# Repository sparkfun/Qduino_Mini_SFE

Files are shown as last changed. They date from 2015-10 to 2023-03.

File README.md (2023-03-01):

Qduino Mini
========================================

Qduino Mini Qduino Mini top view (https://www.sparkfun.com/products/13614)

[*Qduino Mini - Arduino Dev Board (DEV-13614)*](https://www.sparkfun.com/products/13614)

The Qduino Mini is *perfect* to embed in your electronics projects, it's super small, inexpensive, has a battery connector & charger built-in, & a fuel gauge that can tell you when to charge the battery!

The **Qduino Mini is Arduino-compatible & 100% open source, hardware and software** meaning that making and programming your first circuit is a breeze.  Hardware is hard, so we decided to make it a little bit easier.  All of the design files, including EAGLE board files, schematic, and code have been released under an open source license.  Here's what it includes:

* **Battery Charger Circuit** - just plug in USB and it charges the battery with the auto switching circuit - there's no extra charger needed & no digging the battery out of your project so you can charge & program at the same time over USB!
* **Battery Fuel Gauge** - guessing on when your project runs out of juice?  We've got you covered - we have a simple monitor library for your battery so you can remind yourself when it needs a little extra juice.
* **Ultra small, Ultra thin, Ultra light** - The Qduino Mini itself is 0.8in x 1.5in (2cm x 3.9cm) & 0.18oz (5 grams), perfect for quadcopters, drones or high altitude balloon projects.  Both the Qduino Mini and the batteries (LiPos) used to power the board fit are super compact & thin, just right for embedding in your projects.

<h4>Tech Specs:</h4>

* **ATmega32U4 Processor** - Arduino Leonardo Compatible
* 32KB Flash Storage
* 2.5KB SRAM
* 1KB EEPROM
* 3.3V @ 8MHz
* 20 Digital I/O // 14 Dedicated
* 12 Analog Channels // 6 Dedicated
* 7 Digital I/O also PWM channels
* SPI, I2C, UART available
* Two RGB LEDs built-in - one for: Charge Status, TX, RX, and the * other user programmable
* **TPS78233** 3.3V 150mA Regulator
* **MCP73832** LiPo Battery Charger
* **MAX17048** LiPo Battery Fuel Gauge

The Qduino Mini is 100% made in the USA! Every board is made and quality tested at SparkFun Electronics, in Niwot, CO.

Documentation
--------------
* **[Introducing the Qduino Mini!](https://www.sparkfun.com/news/1754)** 
* **[Hookup Guide](https://www.hackster.io/team-qtechknow/qduino-mini-quickstart-guide-8b2d68)** - Basic hookup guide
* **[Hackster.io: Projects](https://www.hackster.io/qtechknow)** - Projects using the Qduino.
* **SparkFun: Projects**
  * **[DIY Light Sculpture](https://learn.sparkfun.com/tutorials/diy-light-sculpture)**
  * **[DIY Light-Up Shoes](https://learn.sparkfun.com/tutorials/diy-light-up-shoes)**
* **[SparkFun Arduino Board Add-on](https://github.com/sparkfun/Arduino_Boards)** - Board Add-on for the Qduino Mini
* **[SparkFun Fritzing Part](https://github.com/sparkfun/Fritzing_Parts/blob/main/products/13614_sfe_qtechknow_qduino_mini_arduino_development_board.fzpz)** - Fritzing diagrams for SparkFun products.
* **[SparkFun Graphical Datasheets](https://github.com/sparkfun/Graphical_Datasheets/tree/master/Datasheets/Qduino)** - Graphical Datasheets for various SparkFun products.

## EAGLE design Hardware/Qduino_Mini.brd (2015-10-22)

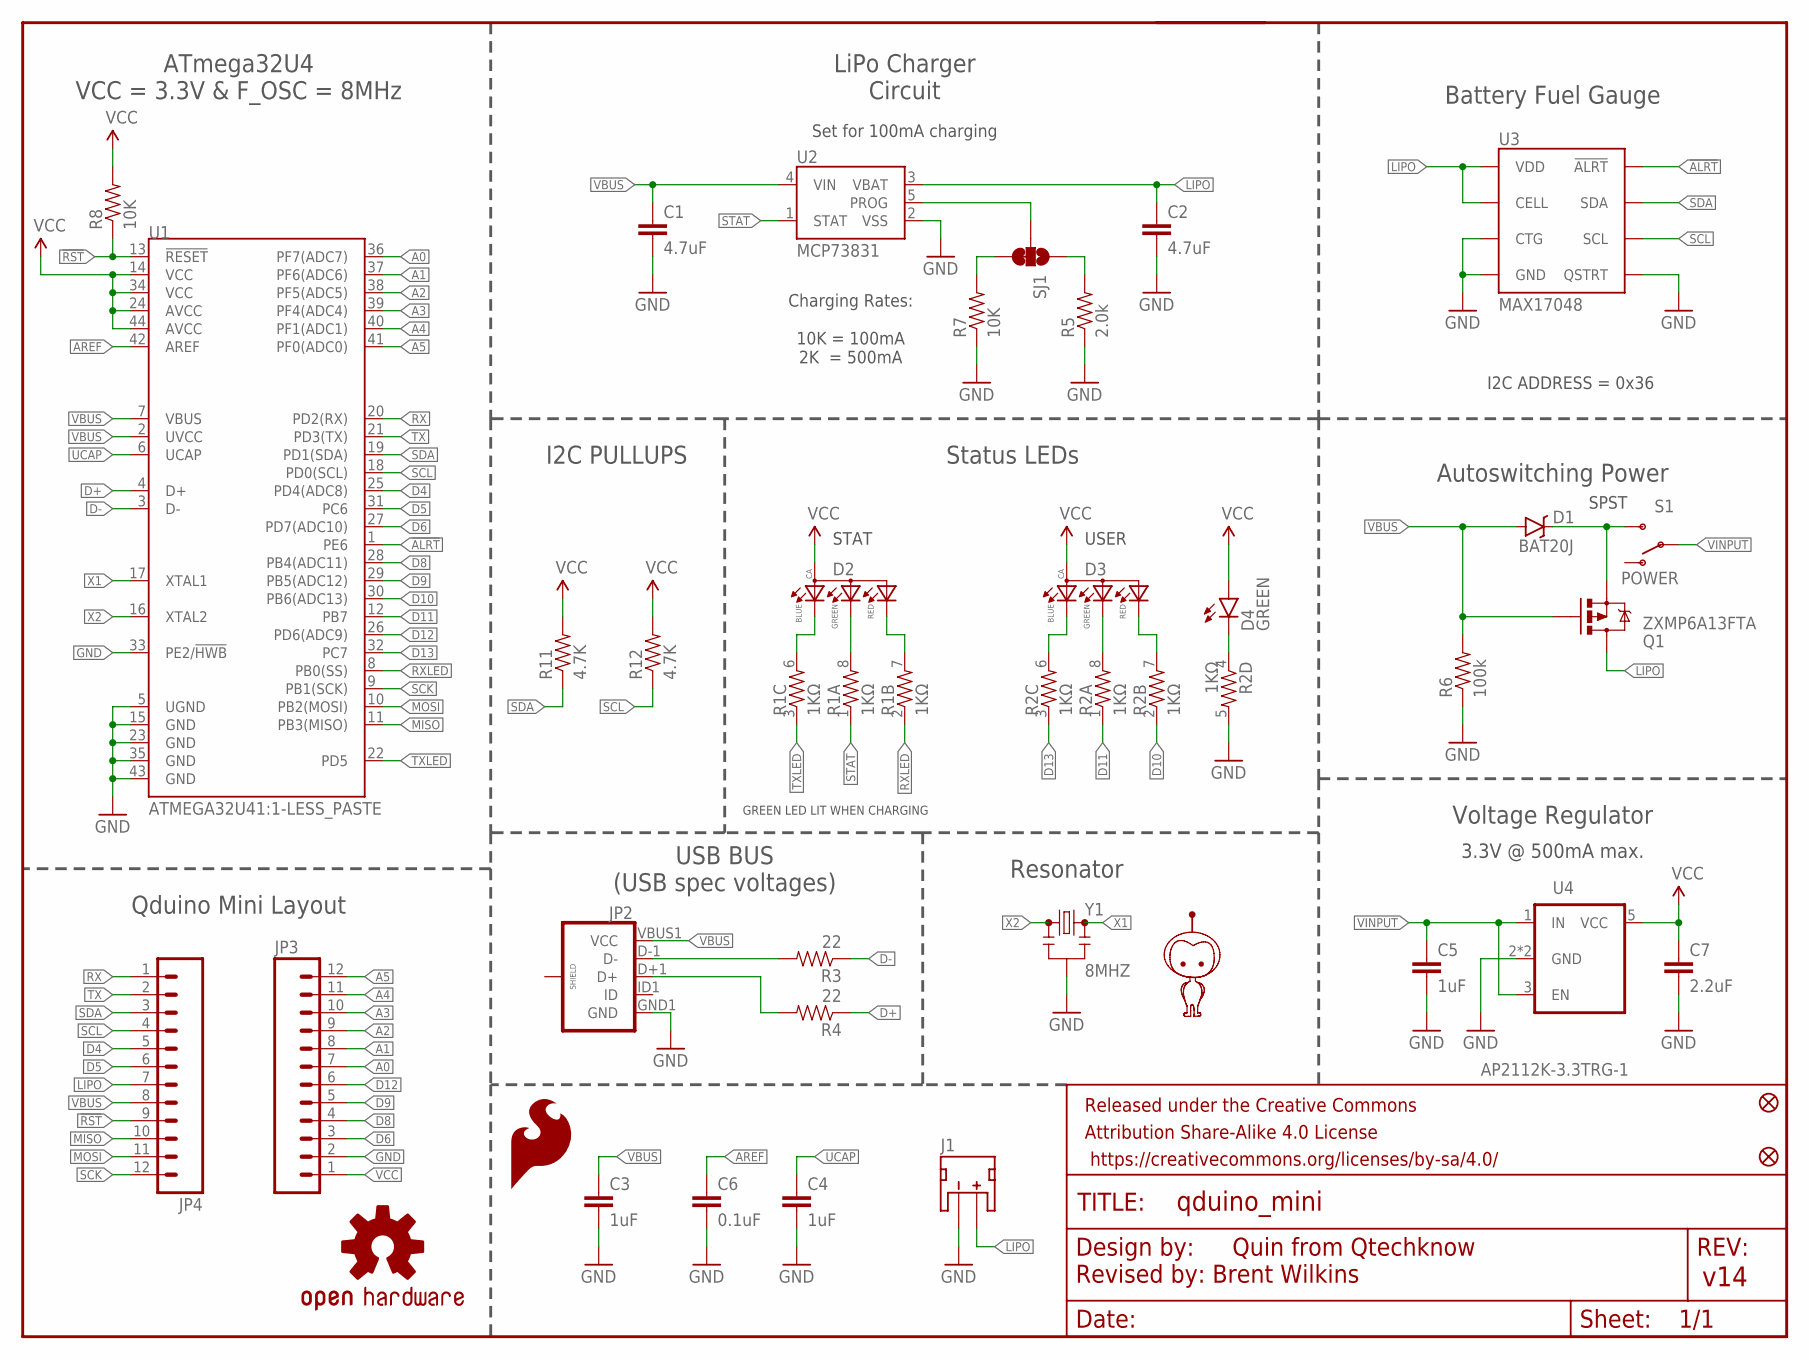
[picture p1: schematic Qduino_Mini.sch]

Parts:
C1, C2: 4.7uF; 0603-CAP
C3, C4, C5: 1uF; 0603-CAP
C6: 0.1uF; 0603-CAP
C7: 2.2uF; 0603-CAP
D1: BAT20J; SOD-323
D2, D3: 0.13_RGB_LEDPLCC; P-LCC-4-3
D4: GREEN; LED-0603
FID1, FID2: FIDUCIALUFIDUCIAL; MICRO-FIDUCIAL
FRAME2: FRAME-LETTER; CREATIVE_COMMONS
J1: LiPo; JST-2-SMD
JP2: USB_MICROB_PLUGCONN-11752; USB-B-MICRO-SMD_V03
JP3, JP4: M12PTH; 1X12
LOGO1: OSHW-LOGOS; OSHW-LOGO-S
LOGO2: SFE_LOGO_FLAME.1_INCH; SFE_LOGO_FLAME_.1
Q1: ZXMP6A13FTA; SOT23-3
R1, R2: 1KΩ; 0603-ARV
R3, R4: 22; 0603-RES
R5: 2.0k; 0603-RES
R6: 100k; 0603-RES
R7, R8: 10K; 0603-RES
R11, R12: 4.7K; 0603-RES
S1: POWER; SWITCH-SPST-SMD-A
SJ1: JUMPER-PAD-3-2OF3_NC_BY_TRACE_SMALL; PAD-JUMPER-3-2OF3_NC_BY_TRACE_YES_SILK_FULL_BOX
U1: ATMEGA32U41:1-LESS_PASTE; QFN-44-NOPAD_1:1-LESS_PASTE
U2: MCP73831; SOT23-5
U3: MAX17048; DFN-8
U4: AP2112K-3.3TRG-1; SOT23-5
U5: MIGHTYQ-L-SILK; LOGO-LARGE-SILK
Y1: 8MHZ; RESONATOR-SMD

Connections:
!ALRT: U1.1 (PE6), U3.P$5 (!ALRT)
!RST: JP4.9, R8.1, U1.13 (!RESET)
A0: JP3.7, U1.36 (PF7(ADC7))
A1: JP3.8, U1.37 (PF6(ADC6))
A2: JP3.9, U1.38 (PF5(ADC5))
A3: JP3.10, U1.39 (PF4(ADC4))
A4: JP3.11, U1.40 (PF1(ADC1))
A5: JP3.12, U1.41 (PF0(ADC0))
AREF: C6.1, U1.42 (AREF)
D4: JP4.5, U1.25 (PD4(ADC8))
D5: JP4.6, U1.31 (PC6)
D6: JP3.3, U1.27 (PD7(ADC10))
D8: JP3.4, U1.28 (PB4(ADC11))
D9: JP3.5, U1.29 (PB5(ADC12))
D10: R2.2 (1), U1.30 (PB6(ADC13))
D11: R2.1, U1.12 (PB7)
D12: JP3.6, U1.26 (PD6(ADC9))
D13: R2.3 (1), U1.32 (PC7)
D+: R4.1, U1.4 (D+)
D-: R3.1, U1.3 (D-)
GND: C1.2, C2.2, C3.2, C4.2, C5.2, C6.2, C7.2, J1.1 (-), JP2.GND1 (GND), JP3.2, R2.5 (2), R5.1, R6.1, R7.1, U1.5 (UGND), U1.15 (GND), U1.23 (GND), U1.33 (PE2/!HWB), U1.35 (GND), U1.43 (GND), U2.2 (VSS), U3.P$1 (CTG), U3.P$4 (GND), U3.P$6 (QSTRT), U3.P$9 (GND), U4.2 (GND), U4.4 (GND), Y1.2
INMOSFET: D1.C, Q1.2 (S), S1.3 (S)
LIPO: C2.1, J1.2 (+), JP4.7, Q1.3 (D), U2.3 (VBAT), U3.P$2 (CELL), U3.P$3 (VDD)
MISO: JP4.10, U1.11 (PB3(MISO))
MOSI: JP4.11, U1.10 (PB2(MOSI))
unnamed: D2.3 (BLUE), R1.6 (2)
unnamed: D2.2 (GREEN), R1.8 (2)
unnamed: D3.3 (BLUE), R2.6 (2)
unnamed: D4.C, R2.4 (1)
unnamed: R7.2, SJ1.3
unnamed: R5.2, SJ1.1
unnamed: D3.2 (GREEN), R2.8 (2)
unnamed: D2.1 (RED), R1.7 (2)
unnamed: D3.1 (RED), R2.7 (2)
PROG: SJ1.2, U2.5 (PROG)
RX: JP4.1, U1.20 (PD2(RX))
RXLED: R1.2 (1), U1.8 (PB0(SS))
SCK: JP4.12, U1.9 (PB1(SCK))
SCL: JP4.4, R12.1, U1.18 (PD0(SCL)), U3.P$7 (SCL)
SDA: JP4.3, R11.1, U1.19 (PD1(SDA)), U3.P$8 (SDA)
STAT: R1.1, U2.1 (STAT)
TX: JP4.2, U1.21 (PD3(TX))
TXLED: R1.3 (1), U1.22 (PD5)
UCAP: C4.1, U1.6 (UCAP)
UD+: JP2.D+1 (D+), R4.2
UD-: JP2.D-1 (D-), R3.2
VBUS: C1.1, C3.1, D1.A, JP2.VBUS1 (VCC), JP4.8, Q1.1 (G), R6.2, U1.2 (UVCC), U1.7 (VBUS), U2.4 (VIN)
VCC: C7.1, D2.4 (ANODE), D3.4 (ANODE), D4.A, JP3.1, R8.2, R11.2, R12.2, U1.14 (VCC), U1.24 (AVCC), U1.34 (VCC), U1.44 (AVCC), U4.5 (VCC)
VINPUT: C5.1, S1.2, U4.1 (IN), U4.3 (EN)
X1: U1.17 (XTAL1), Y1.3
X2: U1.16 (XTAL2), Y1.1

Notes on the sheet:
Set for 100mA charging
USB BUS (USB spec voltages)
Resonator
Status LEDs
3.3V @ 500mA max.
SPST
ATmega32U4 VCC = 3.3V & F_OSC = 8MHz
Qduino Mini Layout
LiPo Charger Circuit
Battery Fuel Gauge
Voltage Regulator
Autoswitching Power
Charging Rates: 10K = 100mA 2K = 500mA
I2C PULLUPS
Revised by: Brent Wilkins
I2C ADDRESS = 0x36
USER
STAT
GREEN LED LIT WHEN CHARGING

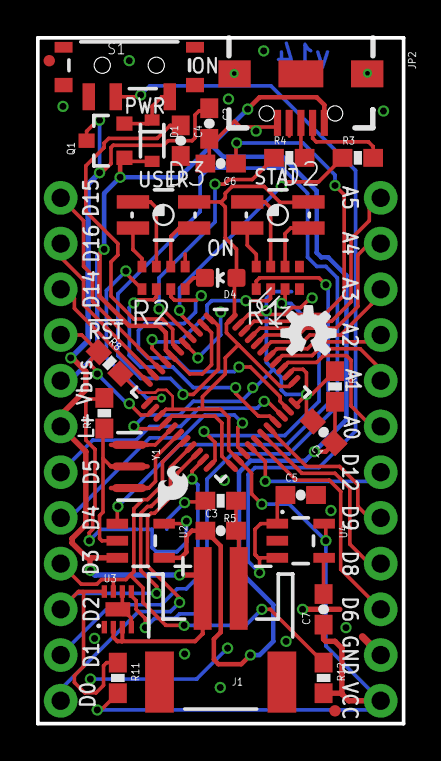
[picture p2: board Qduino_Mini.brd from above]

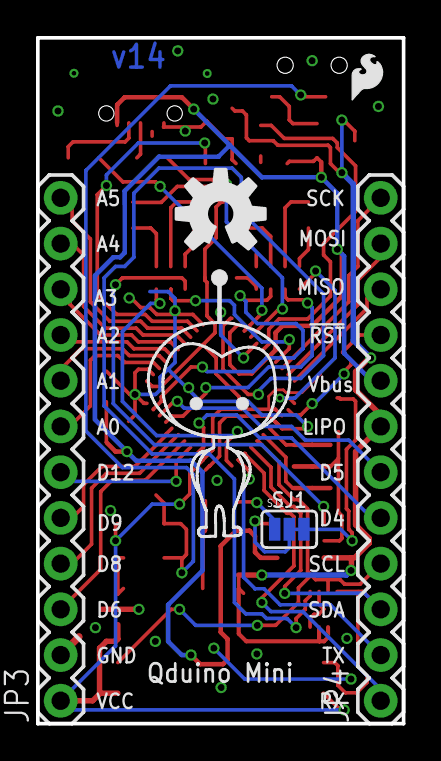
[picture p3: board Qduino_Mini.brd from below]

Board: 2 copper layers, 20.3 x 38.1 mm, 41 parts (6 on the bottom side), 51 nets.

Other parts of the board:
LOGO3: SFE_LOGO_FLAME.1_INCH; SFE_LOGO_FLAME_.1@1
U$4: OSHW-LOGO-M@1

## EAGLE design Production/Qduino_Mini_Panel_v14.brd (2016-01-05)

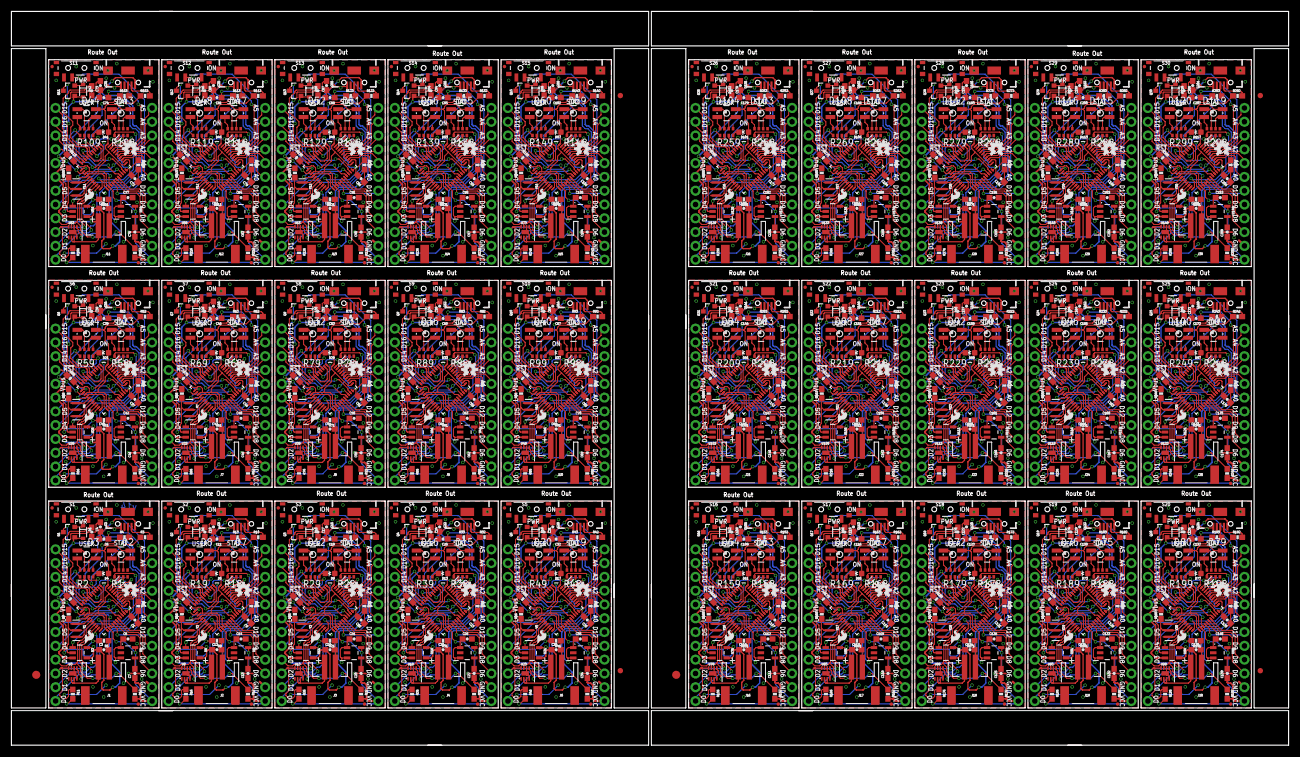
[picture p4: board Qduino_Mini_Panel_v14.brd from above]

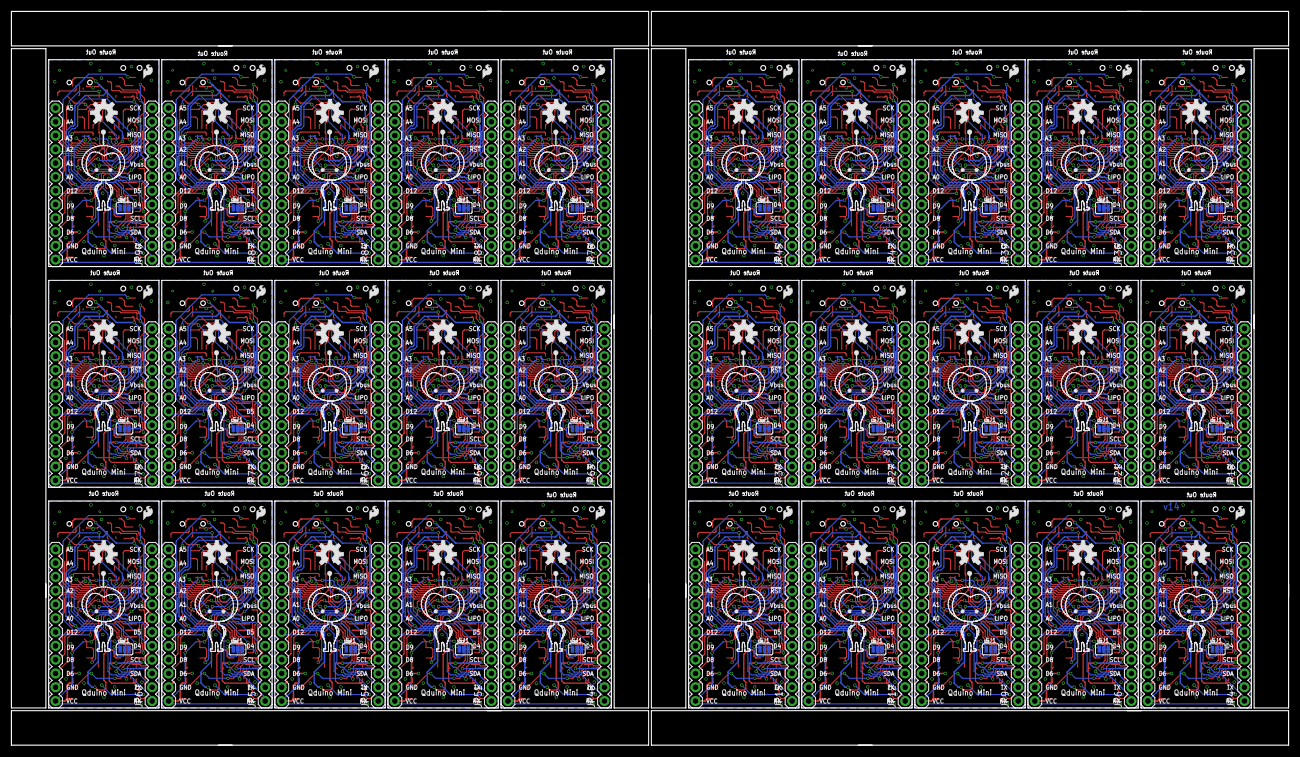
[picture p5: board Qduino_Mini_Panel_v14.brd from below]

Board: 2 copper layers, 235.2 x 135.1 mm, 1206 parts (180 on the bottom side), 1530 nets.

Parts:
C1, C2, C8, C9, C15, C16, C22, C23, C29, C30, C36, C37, C43, C44, C50, C51, C57, C58, C64, C65, C71, C72, C78, C79, C85, C86, C92, C93, C99, C100, C106, C107, C113, C114, C120, C121, C127, C128, C134, C135, C141, C142, C148, C149, C155, C156, C162, C163, C169, C170, C176, C177, C183, C184, C190, C191, C197, C198, C204, C205: 4.7uF; 0603-CAP
C3, C4, C5, C10, C12, C14, C17, C19, C21, C24, C26, C28, C31, C33, C35, C38, C40, C42, C45, C47, C49, C52, C54, C56, C59, C61, C63, C66, C68, C70, C73, C75, C77, C80, C82, C84, C87, C89, C91, C94, C96, C98, C101, C103, C105, C108, C110, C112, C115, C117, C119, C122, C124, C126, C129, C131, C133, C136, C138, C140, C143, C145, C147, C150, C152, C154, C157, C159, C161, C164, C166, C168, C171, C173, C175, C178, C180, C182, C185, C187, C189, C192, C194, C196, C199, C201, C203, C206, C208, C210: 1uF; 0603-CAP
C6, C11, C18, C25, C32, C39, C46, C53, C60, C67, C74, C81, C88, C95, C102, C109, C116, C123, C130, C137, C144, C151, C158, C165, C172, C179, C186, C193, C200, C207: 0.1uF; 0603-CAP
C7, C13, C20, C27, C34, C41, C48, C55, C62, C69, C76, C83, C90, C97, C104, C111, C118, C125, C132, C139, C146, C153, C160, C167, C174, C181, C188, C195, C202, C209: 2.2uF; 0603-CAP
D1, D6, D10, D14, D18, D22, D26, D30, D34, D38, D42, D46, D50, D54, D58, D62, D66, D70, D74, D78, D82, D86, D90, D94, D98, D102, D106, D110, D114, D118: BAT20J; SOD-323
D2, D3, D7, D8, D11, D12, D15, D16, D19, D20, D23, D24, D27, D28, D31, D32, D35, D36, D39, D40, D43, D44, D47, D48, D51, D52, D55, D56, D59, D60, D63, D64, D67, D68, D71, D72, D75, D76, D79, D80, D83, D84, D87, D88, D91, D92, D95, D96, D99, D100, D103, D104, D107, D108, D111, D112, D115, D116, D119, D120: P-LCC-4-3
D4, D5, D9, D13, D17, D21, D25, D29, D33, D37, D41, D45, D49, D53, D57, D61, D65, D69, D73, D77, D81, D85, D89, D93, D97, D101, D105, D109, D113, D117: GREEN; LED-0603
E$1, E$4: FIDUCIAL-1.5X3
E$2, E$3, E$5, E$6: FIDUCIAL-1X2
FID1, FID2, FID3, FID4, FID5, FID6, FID7, FID8, FID9, FID10, FID11, FID12, FID13, FID14, FID15, FID16, FID17, FID18, FID19, FID20, FID21, FID22, FID23, FID24, FID25, FID26, FID27, FID28, FID29, FID30, FID31, FID32, FID33, FID34, FID35, FID36, FID37, FID38, FID39, FID40, FID41, FID42, FID43, FID44, FID45, FID46, FID47, FID48, FID49, FID50, FID51, FID52, FID53, FID54, FID55, FID56, FID57, FID58, FID59, FID60: FIDUCIALUFIDUCIAL; MICRO-FIDUCIAL
J1, J2, J3, J4, J5, J6, J7, J8, J9, J10, J11, J12, J13, J14, J15, J16, J17, J18, J19, J20, J21, J22, J23, J24, J25, J26, J27, J28, J29, J30: LiPo; JST-2-SMD
JP1, JP2, JP7, JP10, JP13, JP16, JP19, JP22, JP25, JP28, JP31, JP34, JP37, JP40, JP43, JP46, JP49, JP52, JP55, JP58, JP61, JP64, JP67, JP70, JP73, JP76, JP79, JP82, JP85, JP88: USB-B-MICRO-SMD_V03
JP3, JP4, JP5, JP6, JP8, JP9, JP11, JP12, JP14, JP15, JP17, JP18, JP20, JP21, JP23, JP24, JP26, JP27, JP29, JP30, JP32, JP33, JP35, JP36, JP38, JP39, JP41, JP42, JP44, JP45, JP47, JP48, JP50, JP51, JP53, JP54, JP56, JP57, JP59, JP60, JP62, JP63, JP65, JP66, JP68, JP69, JP71, JP72, JP74, JP75, JP77, JP78, JP80, JP81, JP83, JP84, JP86, JP87, JP89, JP90: 1X12
LOGO1, LOGO4, LOGO7, LOGO10, LOGO13, LOGO16, LOGO19, LOGO22, LOGO25, LOGO28, LOGO31, LOGO34, LOGO37, LOGO40, LOGO43, LOGO46, LOGO49, LOGO52, LOGO55, LOGO58, LOGO61, LOGO64, LOGO67, LOGO70, LOGO73, LOGO76, LOGO79, LOGO82, LOGO85, LOGO88: OSHW-LOGOS; OSHW-LOGO-S
LOGO2, LOGO5, LOGO8, LOGO11, LOGO14, LOGO17, LOGO20, LOGO23, LOGO26, LOGO29, LOGO32, LOGO35, LOGO38, LOGO41, LOGO44, LOGO47, LOGO50, LOGO53, LOGO56, LOGO59, LOGO62, LOGO65, LOGO68, LOGO71, LOGO74, LOGO77, LOGO80, LOGO83, LOGO86, LOGO89: SFE_LOGO_FLAME.1_INCH; SFE_LOGO_FLAME_.1
LOGO3, LOGO6, LOGO9, LOGO12, LOGO15, LOGO18, LOGO21, LOGO24, LOGO27, LOGO30, LOGO33, LOGO36, LOGO39, LOGO42, LOGO45, LOGO48, LOGO51, LOGO54, LOGO57, LOGO60, LOGO63, LOGO66, LOGO69, LOGO72, LOGO75, LOGO78, LOGO81, LOGO84, LOGO87, LOGO90: SFE_LOGO_FLAME.1_INCH; SFE_LOGO_FLAME_.1@1
Q1, Q2, Q3, Q4, Q5, Q6, Q7, Q8, Q9, Q10, Q11, Q12, Q13, Q14, Q15, Q16, Q17, Q18, Q19, Q20, Q21, Q22, Q23, Q24, Q25, Q26, Q27, Q28, Q29, Q30: ZXMP6A13FTA; SOT23-3
R1, R2, R18, R19, R28, R29, R38, R39, R48, R49, R58, R59, R68, R69, R78, R79, R88, R89, R98, R99, R108, R109, R118, R119, R128, R129, R138, R139, R148, R149, R158, R159, R168, R169, R178, R179, R188, R189, R198, R199, R208, R209, R218, R219, R228, R229, R238, R239, R248, R249, R258, R259, R268, R269, R278, R279, R288, R289, R298, R299: 1KΩ; 0603-ARV
R3, R4, R10, R13, R22, R23, R32, R33, R42, R43, R52, R53, R62, R63, R72, R73, R82, R83, R92, R93, R102, R103, R112, R113, R122, R123, R132, R133, R142, R143, R152, R153, R162, R163, R172, R173, R182, R183, R192, R193, R202, R203, R212, R213, R222, R223, R232, R233, R242, R243, R252, R253, R262, R263, R272, R273, R282, R283, R292, R293: 22; 0603-RES
R5, R9, R21, R31, R41, R51, R61, R71, R81, R91, R101, R111, R121, R131, R141, R151, R161, R171, R181, R191, R201, R211, R221, R231, R241, R251, R261, R271, R281, R291: 2.0k; 0603-RES
R6, R14, R24, R34, R44, R54, R64, R74, R84, R94, R104, R114, R124, R134, R144, R154, R164, R174, R184, R194, R204, R214, R224, R234, R244, R254, R264, R274, R284, R294: 100k; 0603-RES
R7, R8, R15, R20, R25, R30, R35, R40, R45, R50, R55, R60, R65, R70, R75, R80, R85, R90, R95, R100, R105, R110, R115, R120, R125, R130, R135, R140, R145, R150, R155, R160, R165, R170, R175, R180, R185, R190, R195, R200, R205, R210, R215, R220, R225, R230, R235, R240, R245, R250, R255, R260, R265, R270, R275, R280, R285, R290, R295, R300: 10K; 0603-RES
R11, R12, R16, R17, R26, R27, R36, R37, R46, R47, R56, R57, R66, R67, R76, R77, R86, R87, R96, R97, R106, R107, R116, R117, R126, R127, R136, R137, R146, R147, R156, R157, R166, R167, R176, R177, R186, R187, R196, R197, R206, R207, R216, R217, R226, R227, R236, R237, R246, R247, R256, R257, R266, R267, R276, R277, R286, R287, R296, R297: 4.7K; 0603-RES
S1, S2, S3, S4, S5, S6, S7, S8, S9, S10, S11, S12, S13, S14, S15, S16, S17, S18, S19, S20, S21, S22, S23, S24, S25, S26, S27, S28, S29, S30: POWER; SWITCH-SPST-SMD-A
SJ1, SJ2, SJ3, SJ4, SJ5, SJ6, SJ7, SJ8, SJ9, SJ10, SJ11, SJ12, SJ13, SJ14, SJ15, SJ16, SJ17, SJ18, SJ19, SJ20, SJ21, SJ22, SJ23, SJ24, SJ25, SJ26, SJ27, SJ28, SJ29, SJ30: PAD-JUMPER-3-2OF3_NC_BY_TRACE_YES_SILK_FULL_BOX
U1, U7, U12, U17, U22, U27, U32, U37, U42, U47, U52, U57, U62, U67, U72, U77, U82, U87, U92, U97, U102, U107, U112, U117, U122, U127, U132, U137, U142, U147: ATMEGA32U41:1-LESS_PASTE; QFN-44-NOPAD_1:1-LESS_PASTE
U2, U6, U11, U16, U21, U26, U31, U36, U41, U46, U51, U56, U61, U66, U71, U76, U81, U86, U91, U96, U101, U106, U111, U116, U121, U126, U131, U136, U141, U146: MCP73831; SOT23-5
U3, U8, U13, U18, U23, U28, U33, U38, U43, U48, U53, U58, U63, U68, U73, U78, U83, U88, U93, U98, U103, U108, U113, U118, U123, U128, U133, U138, U143, U148: MAX17048; DFN-8
U4, U9, U14, U19, U24, U29, U34, U39, U44, U49, U54, U59, U64, U69, U74, U79, U84, U89, U94, U99, U104, U109, U114, U119, U124, U129, U134, U139, U144, U149: AP2112K-3.3TRG-1; SOT23-5
U5, U10, U15, U20, U25, U30, U35, U40, U45, U50, U55, U60, U65, U70, U75, U80, U85, U90, U95, U100, U105, U110, U115, U120, U125, U130, U135, U140, U145, U150: MIGHTYQ-L-SILK; LOGO-LARGE-SILK
U$1, U$2, U$3, U$4, U$5, U$6, U$7, U$8, U$9, U$10, U$11, U$12, U$13, U$14, U$15, U$16, U$17, U$18, U$19, U$20, U$21, U$22, U$23, U$24, U$25, U$26, U$27, U$28, U$29, U$30: OSHW-LOGO-M@1
Y1, Y2, Y3, Y4, Y5, Y6, Y7, Y8, Y9, Y10, Y11, Y12, Y13, Y14, Y15, Y16, Y17, Y18, Y19, Y20, Y21, Y22, Y23, Y24, Y25, Y26, Y27, Y28, Y29, Y30: 8MHZ; RESONATOR-SMD

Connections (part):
!ALRT: U1.1, U3.P$5
!ALRT1: U7.1, U8.P$5
!ALRT2: U12.1, U13.P$5
!ALRT3: U17.1, U18.P$5
!ALRT4: U22.1, U23.P$5
!ALRT5: U27.1, U28.P$5
!ALRT6: U32.1, U33.P$5
!ALRT7: U37.1, U38.P$5
!ALRT8: U42.1, U43.P$5
!ALRT9: U47.1, U48.P$5
!ALRT10: U52.1, U53.P$5
!ALRT11: U57.1, U58.P$5
!ALRT12: U62.1, U63.P$5
!ALRT13: U67.1, U68.P$5
!ALRT14: U72.1, U73.P$5
!ALRT15: U77.1, U78.P$5
!ALRT16: U82.1, U83.P$5
!ALRT17: U87.1, U88.P$5
!ALRT18: U92.1, U93.P$5
!ALRT19: U97.1, U98.P$5
!ALRT20: U102.1, U103.P$5
!ALRT21: U107.1, U108.P$5
!ALRT22: U112.1, U113.P$5
!ALRT23: U117.1, U118.P$5
!ALRT24: U122.1, U123.P$5
!ALRT25: U127.1, U128.P$5
!ALRT26: U132.1, U133.P$5
!ALRT27: U137.1, U138.P$5
!ALRT28: U142.1, U143.P$5
!ALRT29: U147.1, U148.P$5
!RST: JP4.9, R8.1, U1.13
!RST1: JP6.9, R20.1, U7.13
!RST2: JP9.9, R30.1, U12.13
!RST3: JP12.9, R40.1, U17.13
!RST4: JP15.9, R50.1, U22.13
!RST5: JP18.9, R60.1, U27.13
!RST6: JP21.9, R70.1, U32.13
!RST7: JP24.9, R80.1, U37.13
!RST8: JP27.9, R90.1, U42.13
!RST9: JP30.9, R100.1, U47.13
!RST10: JP33.9, R110.1, U52.13
!RST11: JP36.9, R120.1, U57.13
!RST12: JP39.9, R130.1, U62.13
!RST13: JP42.9, R140.1, U67.13
!RST14: JP45.9, R150.1, U72.13
!RST15: JP48.9, R160.1, U77.13
!RST16: JP51.9, R170.1, U82.13
!RST17: JP54.9, R180.1, U87.13
!RST18: JP57.9, R190.1, U92.13
!RST19: JP60.9, R200.1, U97.13
!RST20: JP63.9, R210.1, U102.13
!RST21: JP66.9, R220.1, U107.13
!RST22: JP69.9, R230.1, U112.13
!RST23: JP72.9, R240.1, U117.13
!RST24: JP75.9, R250.1, U122.13
!RST25: JP78.9, R260.1, U127.13
!RST26: JP81.9, R270.1, U132.13
!RST27: JP84.9, R280.1, U137.13
!RST28: JP87.9, R290.1, U142.13
!RST29: JP90.9, R300.1, U147.13
A0: JP3.7, U1.36
A1: JP3.8, U1.37
A2: JP3.9, U1.38
A3: JP3.10, U1.39
A4: JP3.11, U1.40
A5: JP3.12, U1.41
A6: JP5.7, U7.36
A7: JP5.8, U7.37
A8: JP5.9, U7.38
A9: JP5.10, U7.39
A10: JP5.11, U7.40
A11: JP5.12, U7.41
A12: JP8.7, U12.36
A13: JP8.8, U12.37
A14: JP8.9, U12.38
A15: JP8.10, U12.39
A16: JP8.11, U12.40
A17: JP8.12, U12.41
A18: JP11.7, U17.36
A19: JP11.8, U17.37
A20: JP11.9, U17.38
A21: JP11.10, U17.39
A22: JP11.11, U17.40
A23: JP11.12, U17.41
A24: JP14.7, U22.36
A25: JP14.8, U22.37
A26: JP14.9, U22.38
A27: JP14.10, U22.39
A28: JP14.11, U22.40
A29: JP14.12, U22.41
A30: JP17.7, U27.36
A31: JP17.8, U27.37
A32: JP17.9, U27.38
A33: JP17.10, U27.39
A34: JP17.11, U27.40
A35: JP17.12, U27.41
A36: JP20.7, U32.36
A37: JP20.8, U32.37
A38: JP20.9, U32.38
A39: JP20.10, U32.39
A40: JP20.11, U32.40
A41: JP20.12, U32.41
A42: JP23.7, U37.36
A43: JP23.8, U37.37
A44: JP23.9, U37.38
A45: JP23.10, U37.39
A46: JP23.11, U37.40
A47: JP23.12, U37.41
A48: JP26.7, U42.36
A49: JP26.8, U42.37
A50: JP26.9, U42.38
A51: JP26.10, U42.39
A52: JP26.11, U42.40
A53: JP26.12, U42.41
A54: JP29.7, U47.36
A55: JP29.8, U47.37
A56: JP29.9, U47.38
A57: JP29.10, U47.39
A58: JP29.11, U47.40
A59: JP29.12, U47.41
A60: JP32.7, U52.36
A61: JP32.8, U52.37
A62: JP32.9, U52.38
A63: JP32.10, U52.39
A64: JP32.11, U52.40
A65: JP32.12, U52.41
A66: JP35.7, U57.36
A67: JP35.8, U57.37
A68: JP35.9, U57.38
A69: JP35.10, U57.39
A70: JP35.11, U57.40
A71: JP35.12, U57.41
A72: JP38.7, U62.36
A73: JP38.8, U62.37
A74: JP38.9, U62.38
A75: JP38.10, U62.39
A76: JP38.11, U62.40
A77: JP38.12, U62.41
A78: JP41.7, U67.36
A79: JP41.8, U67.37
A80: JP41.9, U67.38
A81: JP41.10, U67.39
A82: JP41.11, U67.40
A83: JP41.12, U67.41
A84: JP44.7, U72.36
A85: JP44.8, U72.37
A86: JP44.9, U72.38
A87: JP44.10, U72.39
A88: JP44.11, U72.40
A89: JP44.12, U72.41
A90: JP47.7, U77.36
A91: JP47.8, U77.37
A92: JP47.9, U77.38
A93: JP47.10, U77.39
A94: JP47.11, U77.40
A95: JP47.12, U77.41
A96: JP50.7, U82.36
A97: JP50.8, U82.37
A98: JP50.9, U82.38
A99: JP50.10, U82.39
A100: JP50.11, U82.40
A101: JP50.12, U82.41
A102: JP53.7, U87.36
A103: JP53.8, U87.37
A104: JP53.9, U87.38
A105: JP53.10, U87.39
A106: JP53.11, U87.40
A107: JP53.12, U87.41
A108: JP56.7, U92.36
A109: JP56.8, U92.37
A110: JP56.9, U92.38
A111: JP56.10, U92.39
A112: JP56.11, U92.40
A113: JP56.12, U92.41
A114: JP59.7, U97.36
A115: JP59.8, U97.37
A116: JP59.9, U97.38
A117: JP59.10, U97.39
A118: JP59.11, U97.40
A119: JP59.12, U97.41
A120: JP62.7, U102.36
A121: JP62.8, U102.37
A122: JP62.9, U102.38
A123: JP62.10, U102.39
A124: JP62.11, U102.40
A125: JP62.12, U102.41
A126: JP65.7, U107.36
A127: JP65.8, U107.37
A128: JP65.9, U107.38
A129: JP65.10, U107.39
A130: JP65.11, U107.40
A131: JP65.12, U107.41
A132: JP68.7, U112.36
A133: JP68.8, U112.37
A134: JP68.9, U112.38
A135: JP68.10, U112.39
A136: JP68.11, U112.40
A137: JP68.12, U112.41
A138: JP71.7, U117.36
A139: JP71.8, U117.37
A140: JP71.9, U117.38
A141: JP71.10, U117.39
A142: JP71.11, U117.40
A143: JP71.12, U117.41
A144: JP74.7, U122.36
A145: JP74.8, U122.37
A146: JP74.9, U122.38
A147: JP74.10, U122.39
A148: JP74.11, U122.40
A149: JP74.12, U122.41
A150: JP77.7, U127.36
A151: JP77.8, U127.37
A152: JP77.9, U127.38
A153: JP77.10, U127.39
A154: JP77.11, U127.40
A155: JP77.12, U127.41
A156: JP80.7, U132.36
A157: JP80.8, U132.37
A158: JP80.9, U132.38
A159: JP80.10, U132.39
A160: JP80.11, U132.40
A161: JP80.12, U132.41
A162: JP83.7, U137.36
A163: JP83.8, U137.37
A164: JP83.9, U137.38
A165: JP83.10, U137.39
A166: JP83.11, U137.40
A167: JP83.12, U137.41
A168: JP86.7, U142.36
A169: JP86.8, U142.37
A170: JP86.9, U142.38
A171: JP86.10, U142.39
A172: JP86.11, U142.40
A173: JP86.12, U142.41
A174: JP89.7, U147.36
A175: JP89.8, U147.37
A176: JP89.9, U147.38
A177: JP89.10, U147.39
A178: JP89.11, U147.40
A179: JP89.12, U147.41
AREF: C6.1, U1.42
AREF1: C11.1, U7.42
AREF2: C18.1, U12.42
AREF3: C25.1, U17.42
AREF4: C32.1, U22.42
AREF5: C39.1, U27.42
AREF6: C46.1, U32.42
AREF7: C53.1, U37.42
AREF8: C60.1, U42.42
AREF9: C67.1, U47.42
AREF10: C74.1, U52.42
AREF11: C81.1, U57.42
AREF12: C88.1, U62.42
AREF13: C95.1, U67.42
AREF14: C102.1, U72.42
AREF15: C109.1, U77.42
AREF16: C116.1, U82.42
AREF17: C123.1, U87.42
AREF18: C130.1, U92.42
AREF19: C137.1, U97.42
AREF20: C144.1, U102.42
AREF21: C151.1, U107.42
AREF22: C158.1, U112.42
AREF23: C165.1, U117.42
AREF24: C172.1, U122.42
AREF25: C179.1, U127.42
AREF26: C186.1, U132.42
AREF27: C193.1, U137.42
AREF28: C200.1, U142.42
AREF29: C207.1, U147.42
D1: JP6.5, U7.25
D2: JP6.6, U7.31
D3: JP5.4, U7.28
D4: JP4.5, U1.25
D5: JP4.6, U1.31
D6: JP3.3, U1.27
D7: JP5.5, U7.29
D8: JP3.4, U1.28
D9: JP3.5, U1.29
D10: R2.2, U1.30
D11: R2.1, U1.12
D12: JP3.6, U1.26
D13: R2.3, U1.32
D14: R19.2, U7.30
D15: R19.1, U7.12
D16: JP5.6, U7.26
D17: R19.3, U7.32
D18: JP5.3, U7.27
D19: JP9.5, U12.25
D20: JP9.6, U12.31
D21: JP8.4, U12.28
D22: JP8.5, U12.29
D23: R29.2, U12.30
D24: R29.1, U12.12
D25: JP8.6, U12.26
D26: R29.3, U12.32
D27: JP8.3, U12.27
D28: JP12.5, U17.25
D29: JP12.6, U17.31
D30: JP11.4, U17.28
D31: JP11.5, U17.29
D32: R39.2, U17.30
D33: R39.1, U17.12
D34: JP11.6, U17.26
D35: R39.3, U17.32
D36: JP11.3, U17.27
D37: JP15.5, U22.25
D38: JP15.6, U22.31
D39: JP14.4, U22.28
D40: JP14.5, U22.29
D41: R49.2, U22.30
D42: R49.1, U22.12
D43: JP14.6, U22.26
D44: R49.3, U22.32
D45: JP14.3, U22.27
D46: JP18.5, U27.25
D47: JP18.6, U27.31
D48: JP17.4, U27.28
D49: JP17.5, U27.29
D50: R59.2, U27.30
D51: R59.1, U27.12
D52: JP17.6, U27.26
D53: R59.3, U27.32
D54: JP17.3, U27.27
D55: JP21.5, U32.25
D56: JP21.6, U32.31
D57: JP20.4, U32.28
D58: JP20.5, U32.29
D59: R69.2, U32.30
D60: R69.1, U32.12
D61: JP20.6, U32.26
D62: R69.3, U32.32
D63: JP20.3, U32.27
D64: JP24.5, U37.25
D65: JP24.6, U37.31
D66: JP23.4, U37.28
D67: JP23.5, U37.29
D68: R79.2, U37.30
D69: R79.1, U37.12
D70: JP23.6, U37.26
D71: R79.3, U37.32
D72: JP23.3, U37.27
D73: JP27.5, U42.25
D74: JP27.6, U42.31
D75: JP26.4, U42.28
D76: JP26.5, U42.29
D77: R89.2, U42.30
D78: R89.1, U42.12
D79: JP26.6, U42.26
D80: R89.3, U42.32
D81: JP26.3, U42.27
D82: JP30.5, U47.25
D83: JP30.6, U47.31
D84: JP29.4, U47.28
D85: JP29.5, U47.29
D86: R99.2, U47.30
D87: R99.1, U47.12
D88: JP29.6, U47.26
D89: R99.3, U47.32
D90: JP29.3, U47.27
D91: JP33.5, U52.25
D92: JP33.6, U52.31
D93: JP32.4, U52.28
D94: JP32.5, U52.29
D95: R109.2, U52.30
D96: R109.1, U52.12
D97: JP32.6, U52.26
D98: R109.3, U52.32
D99: JP32.3, U52.27
D100: JP36.5, U57.25
D101: JP36.6, U57.31
D102: JP35.4, U57.28
D103: JP35.5, U57.29
D104: R119.2, U57.30
D105: R119.1, U57.12
D106: JP35.6, U57.26
D107: R119.3, U57.32
D108: JP35.3, U57.27
D109: JP39.5, U62.25
D110: JP39.6, U62.31
D111: JP38.4, U62.28
D112: JP38.5, U62.29
D113: R129.2, U62.30
D114: R129.1, U62.12
D115: JP38.6, U62.26
D116: R129.3, U62.32
D117: JP38.3, U62.27
D118: JP42.5, U67.25
D119: JP42.6, U67.31
D120: JP41.4, U67.28
D121: JP41.5, U67.29
D122: R139.2, U67.30
D123: R139.1, U67.12
D124: JP41.6, U67.26
D125: R139.3, U67.32
D126: JP41.3, U67.27
D127: JP45.5, U72.25
D128: JP45.6, U72.31
D129: JP44.4, U72.28
D130: JP44.5, U72.29
D131: R149.2, U72.30
D132: R149.1, U72.12
D133: JP44.6, U72.26
D134: R149.3, U72.32
D135: JP44.3, U72.27
D136: JP48.5, U77.25
D137: JP48.6, U77.31
D138: JP47.4, U77.28
D139: JP47.5, U77.29
D140: R159.2, U77.30
D141: R159.1, U77.12
D142: JP47.6, U77.26
D143: R159.3, U77.32
D144: JP47.3, U77.27
D145: JP51.5, U82.25
D146: JP51.6, U82.31
D147: JP50.4, U82.28
D148: JP50.5, U82.29
D149: R169.2, U82.30
D150: R169.1, U82.12
D151: JP50.6, U82.26
D152: R169.3, U82.32
D153: JP50.3, U82.27
D154: JP54.5, U87.25
D155: JP54.6, U87.31
D156: JP53.4, U87.28
D157: JP53.5, U87.29
D158: R179.2, U87.30
D159: R179.1, U87.12
D160: JP53.6, U87.26
D161: R179.3, U87.32
D162: JP53.3, U87.27
D163: JP57.5, U92.25
D164: JP57.6, U92.31
D165: JP56.4, U92.28
D166: JP56.5, U92.29
D167: R189.2, U92.30
D168: R189.1, U92.12
D169: JP56.6, U92.26
D170: R189.3, U92.32
D171: JP56.3, U92.27
D172: JP60.5, U97.25
D173: JP60.6, U97.31
D174: JP59.4, U97.28
D175: JP59.5, U97.29
D176: R199.2, U97.30
D177: R199.1, U97.12
D178: JP59.6, U97.26
D179: R199.3, U97.32
D180: JP59.3, U97.27
D181: JP63.5, U102.25
D182: JP63.6, U102.31
D183: JP62.4, U102.28
D184: JP62.5, U102.29
D185: R209.2, U102.30
D186: R209.1, U102.12
D187: JP62.6, U102.26
D188: R209.3, U102.32
D189: JP62.3, U102.27
D190: JP66.5, U107.25
D191: JP66.6, U107.31
D192: JP65.4, U107.28
D193: JP65.5, U107.29
D194: R219.2, U107.30
D195: R219.1, U107.12
D196: JP65.6, U107.26
D197: R219.3, U107.32
D198: JP65.3, U107.27
D199: JP69.5, U112.25
D200: JP69.6, U112.31
D201: JP68.4, U112.28
D202: JP68.5, U112.29
D203: R229.2, U112.30
D204: R229.1, U112.12
D205: JP68.6, U112.26
D206: R229.3, U112.32
D207: JP68.3, U112.27
D208: JP72.5, U117.25
D209: JP72.6, U117.31
D210: JP71.4, U117.28
D211: JP71.5, U117.29
D212: R239.2, U117.30
D213: R239.1, U117.12
D214: JP71.6, U117.26
D215: R239.3, U117.32
D216: JP71.3, U117.27
D217: JP75.5, U122.25
D218: JP75.6, U122.31
D219: JP74.4, U122.28
D220: JP74.5, U122.29
D221: R249.2, U122.30
D222: R249.1, U122.12
D223: JP74.6, U122.26
D224: R249.3, U122.32
D225: JP74.3, U122.27
D226: JP78.5, U127.25
D227: JP78.6, U127.31
D228: JP77.4, U127.28
D229: JP77.5, U127.29
D230: R259.2, U127.30
D231: R259.1, U127.12
D232: JP77.6, U127.26
D233: R259.3, U127.32
D234: JP77.3, U127.27
D235: JP81.5, U132.25
D236: JP81.6, U132.31
D237: JP80.4, U132.28
D238: JP80.5, U132.29
D239: R269.2, U132.30
D240: R269.1, U132.12
D241: JP80.6, U132.26
D242: R269.3, U132.32
D243: JP80.3, U132.27
D244: JP84.5, U137.25
D245: JP84.6, U137.31
D246: JP83.4, U137.28
D247: JP83.5, U137.29
D248: R279.2, U137.30
D249: R279.1, U137.12
D250: JP83.6, U137.26
D251: R279.3, U137.32
D252: JP83.3, U137.27
D253: JP87.5, U142.25
D254: JP87.6, U142.31
D255: JP86.4, U142.28
D256: JP86.5, U142.29
D257: R289.2, U142.30
D258: R289.1, U142.12
D259: JP86.6, U142.26
D260: R289.3, U142.32
D261: JP86.3, U142.27
D262: JP90.5, U147.25
D263: JP90.6, U147.31
D264: JP89.4, U147.28
D265: JP89.5, U147.29
D266: R299.2, U147.30
D267: R299.1, U147.12
D268: JP89.6, U147.26
D269: R299.3, U147.32
D270: JP89.3, U147.27
D+: R4.1, U1.4
D+1: R13.1, U7.4
D+2: R23.1, U12.4
D+3: R33.1, U17.4
D+4: R43.1, U22.4
D+5: R53.1, U27.4
D+6: R63.1, U32.4
D+7: R73.1, U37.4
D+8: R83.1, U42.4
D+9: R93.1, U47.4
D+10: R103.1, U52.4
D+11: R113.1, U57.4
D+12: R123.1, U62.4
D+13: R133.1, U67.4
D+14: R143.1, U72.4
D+15: R153.1, U77.4
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

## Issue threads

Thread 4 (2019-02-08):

Battery Won't Charge

Squidman32, 2019-02-08:
I am not able to get my 3.7V 2000mAh patter to charge on my Qduino.  I'm brand new to DIY electronics, so may be missing something. I plugged in board to usb and plugged the battery into the board and left it over night.  It is still at 0% when I check it with qduino FuelGage program, and the battery doesn't power the board on its own.  Is there a way I can do a factory reset or update firmware to see if thats the issue?

bboyho, 2019-02-12:
Hi,

I just noticed your question when browsing this GitHub repository. This seems more like a technical support related question. The Qduino Mini usually is tested and by quality control before it is packaged and sent out. The board has a dedicated LiPo charger set to 100mA by default but I do not think that has anything to do with your LiPo not charging. The firmware has nothing to do with configuring the charge rate but you can monitor the LiPo battery.

If you are using a [3.7V/2000mAh LiPo battery](https://www.sparkfun.com/products/13855) with a built-in protection circuit, it's possible the battery's protection circuit kicked in when if it is under the minimum voltage preventing it from being charged. I would also check your USB cable. If you have further issues, you may want to check with our [technical support](https://www.sparkfun.com/technical_assistance) if you have not already.

Squidman32, 2019-02-12:
Thanks for the help!  Turns out the positive/negative terminals on the batter were the opposite of those on the Qduino.  I manually swapped them around in the jack that came with the battery and now it all works no problem.

bboyho, 2019-03-08:
Cool. That's a first that I have seen with the battery pins reversed. I'm glad to hear that you got it figured out!

Closed 2019-02-12.

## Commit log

2015-02-06 Fork of https://github.com/MightyQ/Qduino-Mini with irrelevant files and versions removed
    [Qduino_Mini.brd, Qduino_Mini.sch]
2015-02-06 Converted simple things to SparkFun styles
    [Qduino_Mini.brd, Qduino_Mini.sch]
2015-02-18 Added pullup resistors, added alrt interrupt trace, added PROD_ID to each part, swapped out SFE already used parts, etc
    [Qduino_Mini.brd, Qduino_Mini.sch]
2015-02-18 Added missing prod_id for switch
    [Qduino_Mini.brd, Qduino_Mini.sch]
2015-02-24 Dropped resonator to 8MHz for battery use & fixed some silk
    [Qduino_Mini.brd, Qduino_Mini.sch]
2015-02-24 Pushed silk around
    [Qduino_Mini.brd, Qduino_Mini.sch]
2015-02-24 Added label to SJ1
    [Qduino_Mini.brd]
2015-02-25 Fixed library caused(?) inconsistencies
    [Qduino_Mini.brd, Qduino_Mini.sch]
2015-02-26 Added logos to sch, massaged silk & a trace
    [Qduino_Mini.brd, Qduino_Mini.sch]
2015-02-26 Added vias to USB connector pads to improve mechanical strength (from what I hear)
    [Qduino_Mini.brd]
2015-04-07 Complete rework
    [Qduino_Mini.brd, Qduino_Mini.sch]
2015-04-07 Fixed PROD_ID on caps again
    [Qduino_Mini.brd, Qduino_Mini.sch]
2015-04-08 Renamed a few parts and removed gnd traces under gnd pours
    [Qduino_Mini.brd, Qduino_Mini.sch]
2015-04-08 Converted more parts to parts SFE uses
    [Qduino_Mini.brd, Qduino_Mini.sch]
2015-04-08 Fixed a little silk
    [Qduino_Mini.brd]
2015-04-14 Labled LED flags to the colors ther were hooked up to and replaced the RGB LEDs with the footprint for the new part. STUFF IS BROKEN.
    [Qduino_Mini.brd, Qduino_Mini.sch]
2015-04-24 Quin reworked the layout to fit the correct footprints for the LEDs he bought
    [Qduino_Mini.brd, Qduino_Mini.sch]
2015-04-24 Added more ground pour, removed acid traps, cosmetic tweaks
    [Qduino_Mini.brd, Qduino_Mini.sch]
2015-04-25 Shifted things, added vias to pads & added more silk.
    [Qduino_Mini.brd]
2015-04-25 internally connected solder jumper, moved traces around new vias on USB
    [Qduino_Mini.brd, Qduino_Mini.sch]
2015-04-25 moved some traces around to make them shorter
    [Qduino_Mini.brd]
2015-04-27 Added note to follow USB spec for USB port
    [Qduino_Mini.sch]
2015-04-27 Removed stray negative label from battery connector
    [Qduino_Mini.sch]
2015-04-27 Removed 4th for-the-user LED, D5 & its current limit resistor
    [Qduino_Mini.brd, Qduino_Mini.sch]
2015-05-08 Added first test of IDE 1.6.4 board support
2015-05-09 Update package_qtechknow_index.json
    Updated Boards menu divider
2015-05-12 bumped BOD level from 2.0V to 2.4V
2015-05-18 Added IC prefix to a part attribute & updated tarball URL to final destination (invalid until repo is public)
    [Qduino_Mini.brd, Qduino_Mini.sch]
2015-05-28 Nudged a little silk and removed battery polarity from the bottom
    [Qduino_Mini.brd]
2015-05-28 Removed castellated vias
    [Qduino_Mini.brd]
2015-05-28 Bumped version to 10
    [Qduino_Mini.brd, Qduino_Mini.sch]
2015-05-29 Improved ground path from LiPo to GND pin nearby. Increased width of LiPo & Vbus by 25-50%
    [Qduino_Mini.brd]
2015-05-29 Fixed issues
    [Qduino_Mini.brd, Qduino_Mini.sch]
2015-05-29 Switched LEDs to those in the live library vs testing
    [Qduino_Mini.brd, Qduino_Mini.sch]
2015-06-01 Moved Arduino board manager code to Software dir
2015-06-02 Updated PROD_ID for Vreg to new part
    [Qduino_Mini.brd, Qduino_Mini.sch]
2015-06-02 Added 10KΩ pull-up to reset line
    [Qduino_Mini.brd, Qduino_Mini.sch]
2015-06-03 Nudged traces and changed orientation of resistor
    Nudged traces and moved 10K resistor for better trace continuity and
    silk arrangement
    [Qduino_Mini.brd, Qduino_Mini.sch]
2015-06-03 Cleaned up silk near recent changes
    [Qduino_Mini.brd, Qduino_Mini.sch]
2015-06-03 Fixed USB silk on bottom
    [Qduino_Mini.brd]
2015-06-05 created panel v10 again
    [Qduino_Mini_Panel_v10.brd]
2015-06-19 RXLED & TXLED were swapped. Noted errata.
    [Qduino_Mini.brd, Qduino_Mini.sch]
2015-07-13 Update boards.txt
    Fixed VIDs
2015-07-13 added drivers to package
2015-07-17 Added notes to schematic & updated board manager files
    [Qduino_Mini.brd, Qduino_Mini.sch]
2015-08-13 Fixed stray PID
2015-08-18 Updated Windows driver setup info file to newer format
2015-08-25 Signed Windows driver
2015-09-03 Fixed MISO D# & powered USB LEDs directly from USB
    [Qduino_Mini.brd, Qduino_Mini.sch]
2015-09-03 Reduced isolate to dramatically increase ground pour
    [Qduino_Mini.brd]
2015-09-04 Incremented version number and panelized
    [Qduino_Mini.brd, Qduino_Mini.sch, Qduino_Mini_Panel_v10.brd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]
2015-09-09 Updated to new DFN-8 pacakge for fuel gauge IC & version++
    [Qduino_Mini.brd, Qduino_Mini.sch]
2015-09-09 Moved resistor arrays 25mil further away from LEDs for rework
    [Qduino_Mini.brd]
2015-09-11 Moved battery silk
    [Qduino_Mini.brd]
2015-09-11 Reduced DFN-8 center pad paste by 40%
    [Qduino_Mini.brd, Qduino_Mini.sch]
2015-09-11 Reduced tstop to center of IPC recommended range (135 µm) rather than toward the wide end
    [Qduino_Mini.brd, Qduino_Mini.sch]
2015-09-23 Kickstarter design with production tweaks. Keeping the flicker for software compatibility reasons
    [Qduino_Mini.brd, Qduino_Mini.sch]
2015-09-23 Incremented version number
    [Qduino_Mini.brd, Qduino_Mini.sch]
2015-09-23 Added tRestrict to prevent copper from going under resonator footprint's tStop
    [Qduino_Mini.brd]
2015-10-22 Removed redundant gnd path on USB
    [Qduino_Mini.brd, Qduino_Mini.sch]
2015-10-28 created panel v14
    [Qduino_Mini_Panel_v11.brd, Qduino_Mini_Panel_v14.brd]
2016-01-05 Updated software version to current version in Kickstarter repo
2016-01-07 Updated image to current version
2016-01-07 Updated pin map with new definitions
2016-01-08 Removed software. It's now maintained in our Arduino_Boards repo

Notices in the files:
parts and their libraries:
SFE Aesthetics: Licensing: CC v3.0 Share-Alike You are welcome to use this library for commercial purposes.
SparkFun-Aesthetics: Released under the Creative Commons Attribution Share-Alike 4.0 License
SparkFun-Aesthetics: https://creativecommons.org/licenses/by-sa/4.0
